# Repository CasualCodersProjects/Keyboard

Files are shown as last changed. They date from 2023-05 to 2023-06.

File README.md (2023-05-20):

# Casual Coders Custom Keyboard
### By Ian
This keyboard is based upon the standard ANSI 104 layout, adding the following additional features:
- An extra row of function keys F13-F24.
- A rotary encoder above the ESC key.
- Three extra keys above prtSC, SCRLK, and Pause.
- A bank of 8 additional keys above the numpad.
- Optional OLED display above the arrow keys.
- Optional Lock indicator LEDs above the numpad.
- QMK Compatible hardware.

## Hardware
This board is based upon the AT90USB1286 for the highest amount of IO from an AVR microcontroller supported by QMK. Additionally, this board is designed around the kahli Cherry MX style hotswap sockets, for easy swapping and customizing of switches. WS2812B-2020 LEDs provide addressable RGB lighting for each key. Lock indicators are also WS2812s. An additional USB Type C port is provided as this board can draw nearly 5 Amps for the LEDs. There is an optional pin that taps power off this input, to allow the MCU to know if aux power is connected. This is mostly untested. It should be fine, but using aux power *may* fry your board. Test this at your own risk.

All hardware is designed in Kicad.

## Software
This board is built for QMK. You're free to use whatever, but I won't be supporting anything else. The default keymap and firmware is provided in the [software](./software) directory of this repository. This is going to take some refinement to ensure all the included ligiting effects are good, all features can work, and certain default behaviors will need to be decided upon. Multiple defaults may be required, as the encoder(s) are optional.

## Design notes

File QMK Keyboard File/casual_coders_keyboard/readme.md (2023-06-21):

# Casual Coders Keyboard 2.0

A 128(9) Key board with encoder, oled, and RGB

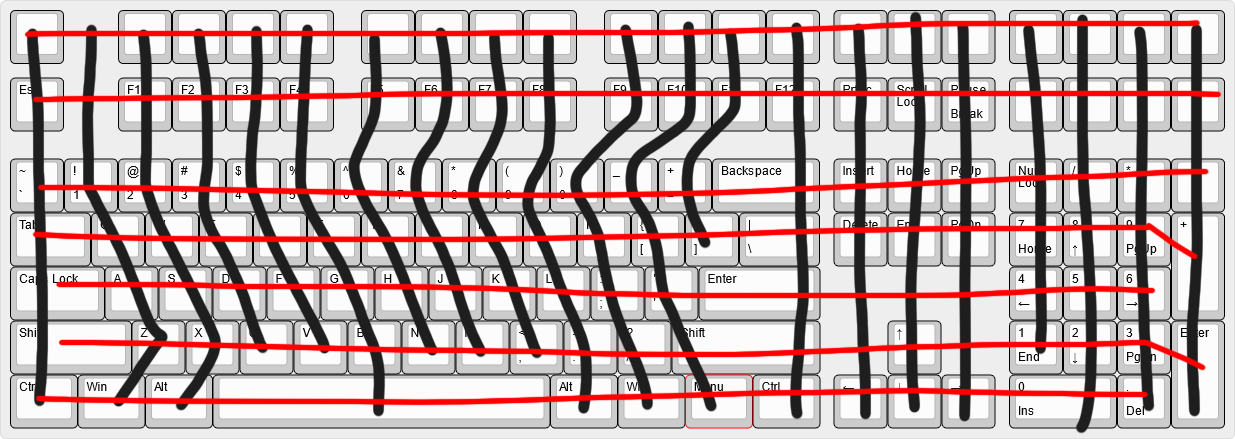
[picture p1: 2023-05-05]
Hardware/layout/Final Layout.png

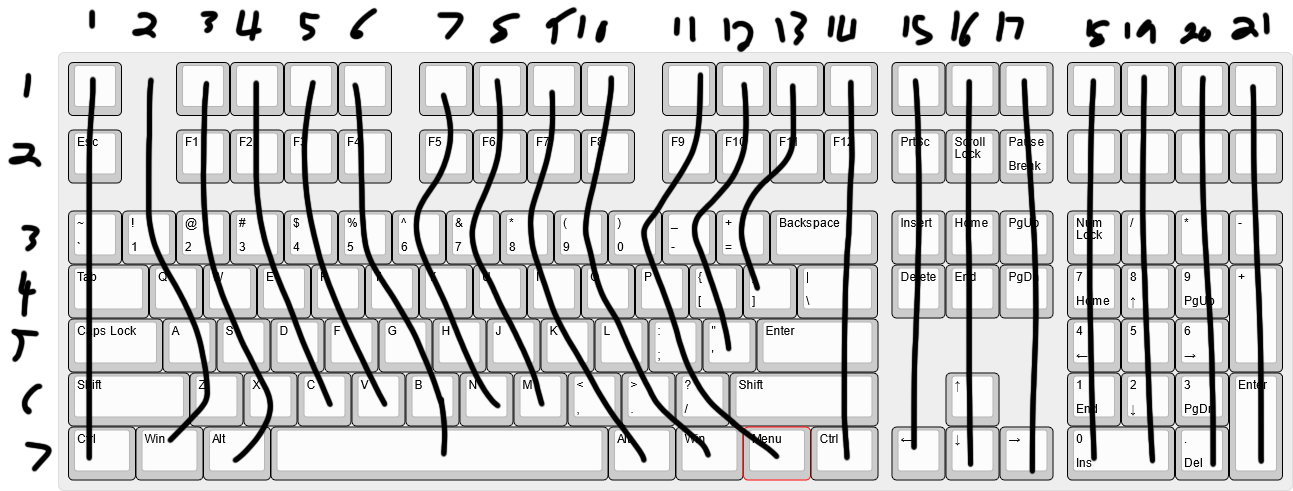
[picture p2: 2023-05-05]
Hardware/layout/keyboard-layout-tentative.png

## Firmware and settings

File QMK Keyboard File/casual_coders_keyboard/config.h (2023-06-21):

/* Copyright 2023
 *
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
 * You should have received a copy of the GNU General Public License
 * along with this program.  If not, see <http://www.gnu.org/licenses/>.
 */
#pragma once

/* key matrix size */
#define MATRIX_ROWS 7
#define MATRIX_COLS 21

// I2C Config
#define I2C_SDA_PIN D1
#define I2C_SCL_PIN D0

// Matrix Pins
#define MATRIX_ROW_PINS { B7, B6, B5, B4, E4, C7, E0 }
#define MATRIX_COL_PINS { A2, A1, F7, F6, F5, F4, F3, F2, C5, A6, A5, A4, A3, A7, C0, C3, D3, D4, D5, D6, D7 }

/* Encoder Setup*/
#define ENCODERS_PAD_A { F1 }
#define ENCODERS_PAD_B { F0 }

/* COL2ROW, ROW2COL*/
#define DIODE_DIRECTION COL2ROW

// RGB Matrix Configuration
#define WS2812_DI_PIN E6
#define RGB_MATRIX_LED_COUNT 131


#define RGBLIGHT_EFFECT_BREATHING
#define RGBLIGHT_EFFECT_RAINBOW_MOOD
#define RGBLIGHT_EFFECT_RAINBOW_SWIRL
#define RGBLIGHT_EFFECT_SNAKE
#define RGBLIGHT_EFFECT_KNIGHT
#define RGBLIGHT_EFFECT_CHRISTMAS
#define RGBLIGHT_EFFECT_STATIC_GRADIENT
#define RGBLIGHT_EFFECT_RGB_TEST
#define RGBLIGHT_EFFECT_ALTERNATING
#define ENABLE_RGB_MATRIX_ALPHAS_MODS
#define ENABLE_RGB_MATRIX_GRADIENT_UP_DOWN 
#define ENABLE_RGB_MATRIX_GRADIENT_LEFT_RIGHT
#define ENABLE_RGB_MATRIX_BREATHING
#define ENABLE_RGB_MATRIX_BAND_SAT
#define ENABLE_RGB_MATRIX_BAND_VAL
#define ENABLE_RGB_MATRIX_BAND_PINWHEEL_SAT
#define ENABLE_RGB_MATRIX_BAND_PINWHEEL_VAL
#define ENABLE_RGB_MATRIX_BAND_SPIRAL_SAT
#define ENABLE_RGB_MATRIX_BAND_SPIRAL_VAL
#define ENABLE_RGB_MATRIX_CYCLE_ALL
#define ENABLE_RGB_MATRIX_CYCLE_LEFT_RIGHT
#define ENABLE_RGB_MATRIX_CYCLE_UP_DOWN
#define ENABLE_RGB_MATRIX_RAINBOW_MOVING_CHEVRON
#define ENABLE_RGB_MATRIX_CYCLE_OUT_IN 
#define ENABLE_RGB_MATRIX_CYCLE_OUT_IN_DUAL
#define ENABLE_RGB_MATRIX_CYCLE_PINWHEEL
#define ENABLE_RGB_MATRIX_CYCLE_SPIRAL
#define ENABLE_RGB_MATRIX_DUAL_BEACON
#define ENABLE_RGB_MATRIX_RAINBOW_BEACON
#define ENABLE_RGB_MATRIX_RAINBOW_PINWHEELS
#define ENABLE_RGB_MATRIX_RAINDROPS
#define ENABLE_RGB_MATRIX_JELLYBEAN_RAINDROPS 
#define ENABLE_RGB_MATRIX_HUE_BREATHING
#define ENABLE_RGB_MATRIX_HUE_PENDULUM
#define ENABLE_RGB_MATRIX_HUE_WAVE 
#define ENABLE_RGB_MATRIX_PIXEL_FRACTAL 
#define ENABLE_RGB_MATRIX_PIXEL_FLOW
#define ENABLE_RGB_MATRIX_PIXEL_RAIN

/*
 * Force NKRO
 *
 * Force NKRO (nKey Rollover) to be enabled by default, regardless of the saved
 * state in the bootmagic EEPROM settings. (Note that NKRO must be enabled in the
 * makefile for this to work.)
 *
 * If forced on, NKRO can be disabled via magic key (default = LShift+RShift+N)
 * until the next keyboard reset.
 *
 * NKRO may prevent your keystrokes from being detected in the BIOS, but it is
 * fully operational during normal computer usage.
 *
 * For a less heavy-handed approach, enable NKRO via magic key (LShift+RShift+N)
 * or via bootmagic (hold SPACE+N while plugging in the keyboard). Once set by
 * bootmagic, NKRO mode will always be enabled until it is toggled again during a
 * power-up.
 *
 */
#define FORCE_NKRO

/*
 * Feature disable options
 *  These options are also useful to firmware size reduction.
 */

/* disable debug print */
//#define NO_DEBUG

/* disable print */
//#define NO_PRINT

/* disable action features */
//#define NO_ACTION_LAYER
//#define NO_ACTION_TAPPING
//#define NO_ACTION_ONESHOT

/* Bootmagic Lite key configuration */
// #define BOOTMAGIC_LITE_ROW 0
// #define BOOTMAGIC_LITE_COLUMN 0

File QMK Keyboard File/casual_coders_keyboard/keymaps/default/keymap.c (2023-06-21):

#include QMK_KEYBOARD_H
#include <stdio.h>
char wpm_str[10];

// Layer names
#define _BASE 0
#define _FUNC1 1

// Main Keyboard Keymaps and Layers.
const uint16_t PROGMEM keymaps[][MATRIX_ROWS][MATRIX_COLS] = {
  [_BASE] = LAYOUT(
    MO(_FUNC1),           KC_F13, KC_F14, KC_F15, KC_F16, KC_F17, KC_F18, KC_F19,  KC_F20,  KC_F21,  KC_F22,  KC_F23,  KC_F24,    KC_MPRV,  KC_MPLY, KC_MNXT,  RGB_HUI,   RGB_HUD,   RGB_MOD,  RGB_RMOD,
    KC_ESC,           KC_F1,  KC_F2,  KC_F3,  KC_F4,  KC_F5,  KC_F6,  KC_F7,   KC_F8,   KC_F9,   KC_F10,  KC_F11,  KC_F12,    KC_PSCR, KC_SCROLL_LOCK, KC_PAUS,   KC_MUTE, KC_VOLD, KC_VOLU, KC_SLEP,
    KC_GRV,  KC_1,    KC_2,   KC_3,   KC_4,   KC_5,   KC_6,   KC_7,   KC_8,    KC_9,    KC_0,    KC_MINS, KC_EQL,  KC_BSPC,   KC_INS,  KC_HOME, KC_PGUP,   KC_NUM_LOCK, KC_PSLS, KC_PAST, KC_PMNS,
    KC_TAB,  KC_Q,    KC_W,   KC_E,   KC_R,   KC_T,   KC_Y,   KC_U,   KC_I,    KC_O,    KC_P,    KC_LBRC, KC_RBRC, KC_BSLS,   KC_DEL,  KC_END,  KC_PGDN,   KC_P7,   KC_P8,   KC_P9,   KC_PPLS,
    KC_CAPS, KC_A,    KC_S,   KC_D,   KC_F,   KC_G,   KC_H,   KC_J,   KC_K,    KC_L,    KC_SCLN, KC_QUOT,          KC_ENT,                                 KC_P4,   KC_P5,   KC_P6,
    KC_LSFT, KC_Z,    KC_X,   KC_C,   KC_V,   KC_B,   KC_N,   KC_M,   KC_COMM, KC_DOT,  KC_SLSH,                   KC_RSFT,            KC_UP,              KC_P1,   KC_P2,   KC_P3,   KC_PENT,
    KC_LCTL, KC_LGUI, KC_LALT,                KC_SPC,                          KC_RALT, KC_RGUI, KC_NO,            KC_RCTL,   KC_LEFT, KC_DOWN, KC_RGHT,            KC_P0,   KC_PDOT
  ),

  [_FUNC1] = LAYOUT(
    KC_NO,           KC_F13, KC_F14, KC_F15, KC_F16, KC_F17, KC_F18, KC_F19,  KC_F20,  KC_F21,  KC_F22,  KC_F23,  KC_F24,    KC_MPRV,  KC_MPLY, KC_MNXT,  RGB_HUI,   RGB_HUD,   RGB_MOD,  RGB_RMOD,
    KC_ESC,           KC_F1,  KC_F2,  KC_F3,  KC_F4,  KC_F5,  KC_F6,  KC_F7,   KC_F8,   KC_F9,   KC_F10,  KC_F11,  KC_F12,    KC_PSCR, KC_SCROLL_LOCK, KC_PAUS,   KC_MUTE, KC_VOLD, KC_VOLU, KC_SLEP,
    KC_GRV,  KC_1,    KC_2,   KC_3,   KC_4,   KC_5,   KC_6,   KC_7,   KC_8,    KC_9,    KC_0,    KC_MINS, KC_EQL,  KC_BSPC,   KC_INS,  KC_HOME, KC_PGUP,   KC_NUM_LOCK, KC_PSLS, KC_PAST, KC_PMNS,
    KC_TAB,  KC_Q,    KC_W,   KC_E,   KC_R,   KC_T,   KC_Y,   KC_U,   KC_I,    KC_O,    KC_P,    KC_LBRC, KC_RBRC, KC_BSLS,   KC_DEL,  KC_END,  KC_PGDN,   KC_P7,   KC_P8,   KC_P9,   KC_PPLS,
    KC_CAPS, KC_A,    KC_S,   KC_D,   KC_F,   KC_G,   KC_H,   KC_J,   KC_K,    KC_L,    KC_SCLN, KC_QUOT,          KC_ENT,                                 KC_P4,   KC_P5,   KC_P6,
    KC_LSFT, KC_Z,    KC_X,   KC_C,   KC_V,   KC_B,   KC_N,   KC_M,   KC_COMM, KC_DOT,  KC_SLSH,                   KC_RSFT,            KC_UP,              KC_P1,   KC_P2,   KC_P3,   KC_PENT,
    KC_LCTL, KC_LGUI, KC_LALT,                KC_SPC,                          KC_RALT, KC_RGUI, KC_NO,            KC_RCTL,   KC_LEFT, KC_DOWN, KC_RGHT,            KC_P0,   KC_PDOT
  ),
};

// Encoder Layers
const uint16_t PROGMEM encoder_map[][NUM_ENCODERS][2] = {
    [_BASE] =   { ENCODER_CCW_CW(KC_MS_WH_LEFT, KC_MS_WH_RIGHT) },
    [_FUNC1] =   { ENCODER_CCW_CW(RGB_VAD, RGB_VAI) },
};

led_config_t g_led_config = { {
  // Key Matrix to LED Index
  {   0, NO_LED, 1, 2, 3, 4, 5, 6, 7, 8, 9, 10, 11, 12, 13, 14, 15, 16, 17, 18, 19 },                       // Row1
  {   39, NO_LED, 38, 37, 36, 35, 34, 33, 32, 31, 30, 28, 28, 27, 26, 25, 24, 23, 22, 21, 20 },             // Row2
  {   40, 41, 42, 43, 44, 45, 46, 47, 48, 49, 50, 51, 52, 53, 54, 55, 56, 57, 58, 59, 60 },                 // Row3
  {   81, 80, 79, 78, 77, 76, 75, 74, 73, 72, 71, 70, 69, 68, 67, 66, 65, 64, 63, 62, 61 },                 //Row4
  {   82, 83, 84, 85, 86, 87, 88, 89, 90, 91, 92, 93, NO_LED, 94, NO_LED, NO_LED, NO_LED, 95, 96, 97, NO_LED }, 
  // {   114, 113, 112, 111, 110, 109, 108, 107, 106, 105, 104, NO_LED, 103, NO_LED, 102, NO_LED, 101, 100, 99, 98 },
  {   115, 116, 117, NO_LED, NO_LED, 118, NO_LED, NO_LED, NO_LED, 119, 120, 121, NO_LED, 122, 123, 124, 125, NO_LED, 126, 127, NO_LED },

}, {
  // LED Index to Physical Position
  { 0,  0 }, { 22,  0 }, { 34, 0 }, { 45,  0 }, { 56, 0 }, { 67,  0 }, { 78,  0 }, { 90,  0 }, { 101,  0 }, { 112,  0 }, { 123,  0 }, { 134,  0 }, { 146,  0 }, { 157,  0 }, { 168,  0 }, { 179,  0 }, { 190,  0 }, { 201,  0 }, { 213,  0 }, { 224,  0 },
  { 224, 11 }, { 213, 11 }, { 201, 11 }, {190, 11 }, { 179, 11 }, { 168, 11 }, { 157, 11 }, { 146, 11 }, { 134, 11 }, { 123, 11 }, { 112, 11 }, { 101, 11 }, { 90, 11 }, { 78, 11 }, { 67,  0 }, { 56, 11 }, { 45, 11 }, { 34, 11 }, { 22, 11 }, { 0, 11 },
  { 0, 21 }, { 11, 21 }, { 22, 21 }, { 34, 21 }, { 45, 21 }, { 56, 21 }, { 67, 21 }, { 78, 21 }, { 90, 21 }, { 101, 21 }, { 112, 21 }, { 123, 21 }, { 134, 21 }, { 146, 21 }, { 157, 21 }, { 168, 21 }, { 179, 21 }, { 190, 21 }, { 201, 21 }, { 213, 21 }, { 224, 21 },
  { 224, 38 }, { 213, 32 }, { 201, 32 }, { 190, 32 }, { 179, 32 }, { 168, 32 }, { 157, 32 }, { 146, 32 }, { 134, 32 }, { 123, 32 }, { 112, 32 }, { 101, 32 }, { 90, 32 }, { 78, 32 }, { 67, 32 }, { 56, 32 }, { 45, 32 }, { 34, 32 }, { 22, 32 }, { 11, 32 }, { 0, 32 },
  { 0, 43 }, { 11, 43 }, { 11, 43 }, { 34, 43 }, { 45, 43 }, { 56, 43 }, { 67, 43 }, { 78, 43 }, { 90, 43 }, { 101, 43 }, { 112, 43 }, { 123, 43 }, { 146, 43 }, { 190, 43 }, { 201, 43 }, { 213, 43 },
  { 224, 58 }, { 213, 53 }, { 201, 53 }, { 190, 53 }, { 168, 53 }, { 146, 53 }, { 123, 53 }, { 112, 53 }, { 101, 53 }, { 90, 53 }, { 78, 53 }, { 67, 53 }, { 56, 53 }, { 45, 53 }, { 34, 53 }, { 22, 53 }, { 11, 53 }, { 0, 53 },
  { 0, 64 }, { 11, 64 }, { 28, 64 }, { 67, 64 }, { 101, 64 }, { 112, 64 }, { 123, 64 }, { 146, 64 }, { 157, 64 }, { 168, 64 }, { 179, 64 }, { 195, 64 }, { 213, 64 }
}, {
  // LED Index to Flag
  4, 4, 4, 4, 4, 4, 4, 4, 4, 4, 4, 4, 4, 4, 4, 4, 4, 4, 4, 4, 
  4, 4, 4, 4, 4, 4, 4, 4, 4, 4, 4, 4, 4, 4, 4, 4, 4, 4, 4, 4,
  4, 4, 4, 4, 4, 4, 4, 4, 4, 4, 4, 4, 4, 4, 4, 4, 4, 4, 4, 4, 4,
  4, 4, 4, 4, 4, 4, 4, 4, 4, 4, 4, 4, 4, 4, 4, 4, 4, 4, 4, 4, 4,
  4, 4, 4, 4, 4, 4, 4, 4, 4, 4, 4, 4, 4, 4, 4, 4,
  4, 4, 4, 4, 4, 4, 4, 4, 4, 4, 4, 4, 4, 4, 4, 4, 4, 4,
  4, 4, 4, 4, 4, 4, 4, 4, 4, 4, 4, 4, 4
} };


// Bongo Cat Section
#ifdef OLED_ENABLE
oled_rotation_t oled_init_user(oled_rotation_t rotation) {
  return OLED_ROTATION_180;  // flips the display 180 degrees if offhand
}
// WPM-responsive animation stuff here
#    define IDLE_FRAMES 5
#    define IDLE_SPEED 20  // below this wpm value your animation will idle

// #define PREP_FRAMES 1 // uncomment if >1

#    define TAP_FRAMES 2
#    define TAP_SPEED 40  // above this wpm value typing animation to trigger

#    define ANIM_FRAME_DURATION 200  // how long each frame lasts in ms
// #define SLEEP_TIMER 60000 // should sleep after this period of 0 wpm, needs fixing
#    define ANIM_SIZE 636  // number of bytes in array, minimize for adequate firmware size, max is 1024
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

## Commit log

2023-05-05 Begin design work. Schema and footprint updates, new layout begun. LEDs and clean traces remain.
    [100p-keebored.kicad_sch, LEDs.kicad_sch, matrix.kicad_sch]
2023-05-05 Repair Folder Structure
    [100p-keebored.kicad_sch, LEDs.kicad_sch, matrix.kicad_sch]
2023-05-05 LED positions finalized. Begin Placement
2023-05-08 general layout complete. trace routing and minir tweaks remain
    [100p-keebored.kicad_sch]
2023-05-20 Massive Progress
    - Completed general layout. I believe this should function as a full keyboard.
    - Missing Caps/Num/Scroll Lock Indicators (LEDS). OLED can take this up, but should we look into adding these? If so, where?
    - Tempted to add a second optional encoder to the top right of the board as well.
    - All I can think of at the moment, but there may be more.
    [100p-keebored-B_Cu.gbr, 100p-keebored-B_Mask.gbr, 100p-keebored-B_Paste.gbr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]
2023-05-20 Massive progress. Should be complete. Pending review. Possible additions: Caps-Num-Scr lock LEDs, second optioal encoder
2023-06-11 Final design for v2.0
    [100p-keebored-B_Cu.gbr, 100p-keebored-B_Mask.gbr, 100p-keebored-B_Paste.gbr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]
2023-06-21 Increment to Rev 2.1, Fix Lock Indicators, Repair Ground Connection D280, move covered mount hole.
    [100p-keebored-B_Cu.gbr, 100p-keebored-B_Mask.gbr, 100p-keebored-B_Paste.gbr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]
2023-06-21 Final design for v2.1
    [100p-keebored-B_Cu.gbr, 100p-keebored-B_Mask.gbr, 100p-keebored-B_Paste.gbr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]

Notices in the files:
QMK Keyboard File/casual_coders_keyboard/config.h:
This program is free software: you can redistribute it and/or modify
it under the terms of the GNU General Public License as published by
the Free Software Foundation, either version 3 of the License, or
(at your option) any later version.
